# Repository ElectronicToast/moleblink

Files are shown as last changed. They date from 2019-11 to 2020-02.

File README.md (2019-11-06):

# moleblink
  

ATtiny85-based illuminated PCB keychain featuring the Blacker Hovse crest

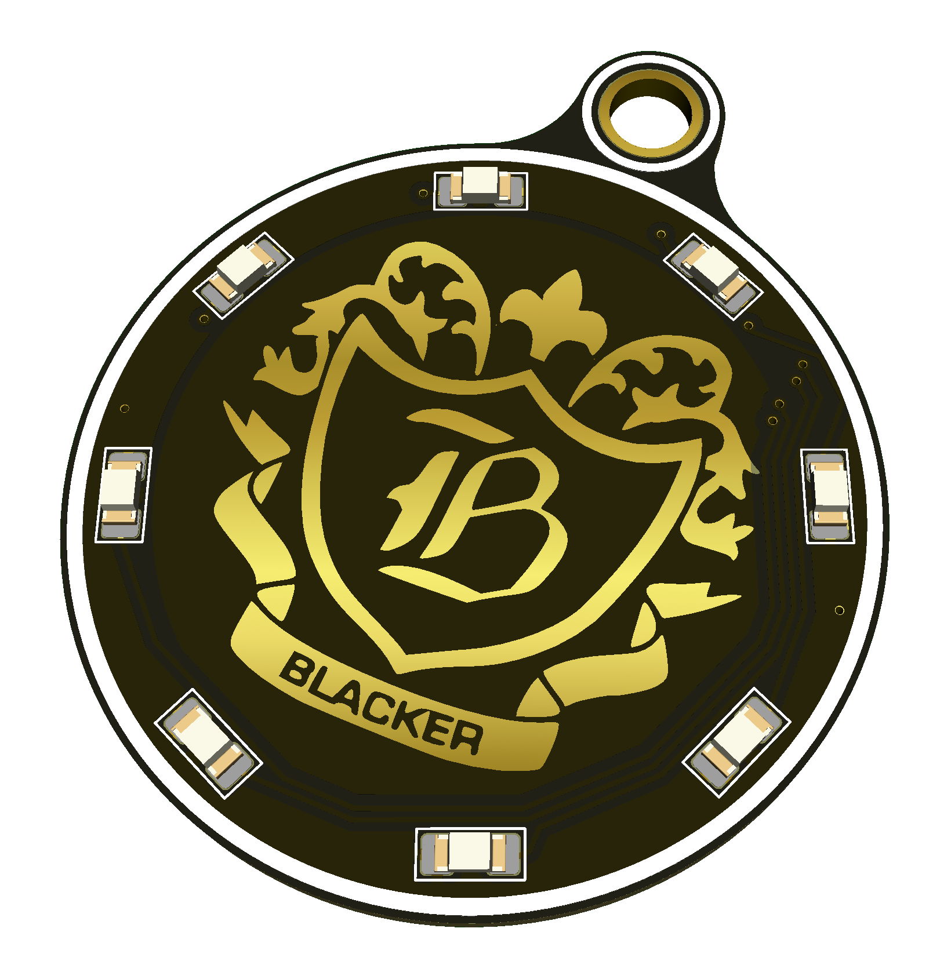
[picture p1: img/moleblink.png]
moleblink


## Description
Blacker Hovse (House) is one of the eight student houses in the undergraduate housing system at Caltech. Blacker was founded in 1932 and named after Robert Roe Blacker, a trustee of Caltech. Notable alumni from Blacker include William Shockley, Walter Munk, Carver Mead, and Kip Thorne. The current house motto is *Sed nvlla nisi ardva virtvs*.

This is a 1.6" by 1.9" PCB keychain featuring the Blacker Hovse crest on the top copper, based on [RuddBlink](https://github.com/ElectronicToast/ruddblink/). A ring of 8 LEDs around the crest is controlled by an ATtiny85 through a 74HC595 shift register. This keychain is intended to be compact and aesthetic, but also simple to solder; all packages are SOIC and 0805 or larger.

The keychain can be powered by a single CR2032 coin cell through the coin cell holder footprint on the back, or through an alternative power source soldered to those pads.

## Features
- ATtiny85 in SOIC-8 package driving 74HC595 shift register in SOIC-16 package
- PWM-able output
- Power switch
- User pushbutton
- MOSFET polarity protection
- PTC fuse
- Aesthetics

## Notes

No input voltage regulation is present. Do not apply more than 5.5 V, the maximum voltage for the ATtiny.

This PCB is designed with KiCad EDA 5.1.4. Schematic and board files may be found under `/moleblink`, with documentation under `/moleblink/doc`.

## Author
- Ray Sun - Undergraduate, Electrical Engineering, Caltech, Class of 2020

## License
<br />Unless otherwise noted, this schematic and PCB design, with associated symbol and footprint files, are licensed under a <a rel="license" href="http://creativecommons.org/licenses/by-sa/4.0/">Creative Commons Attribution-ShareAlike 4.0 International License</a>.

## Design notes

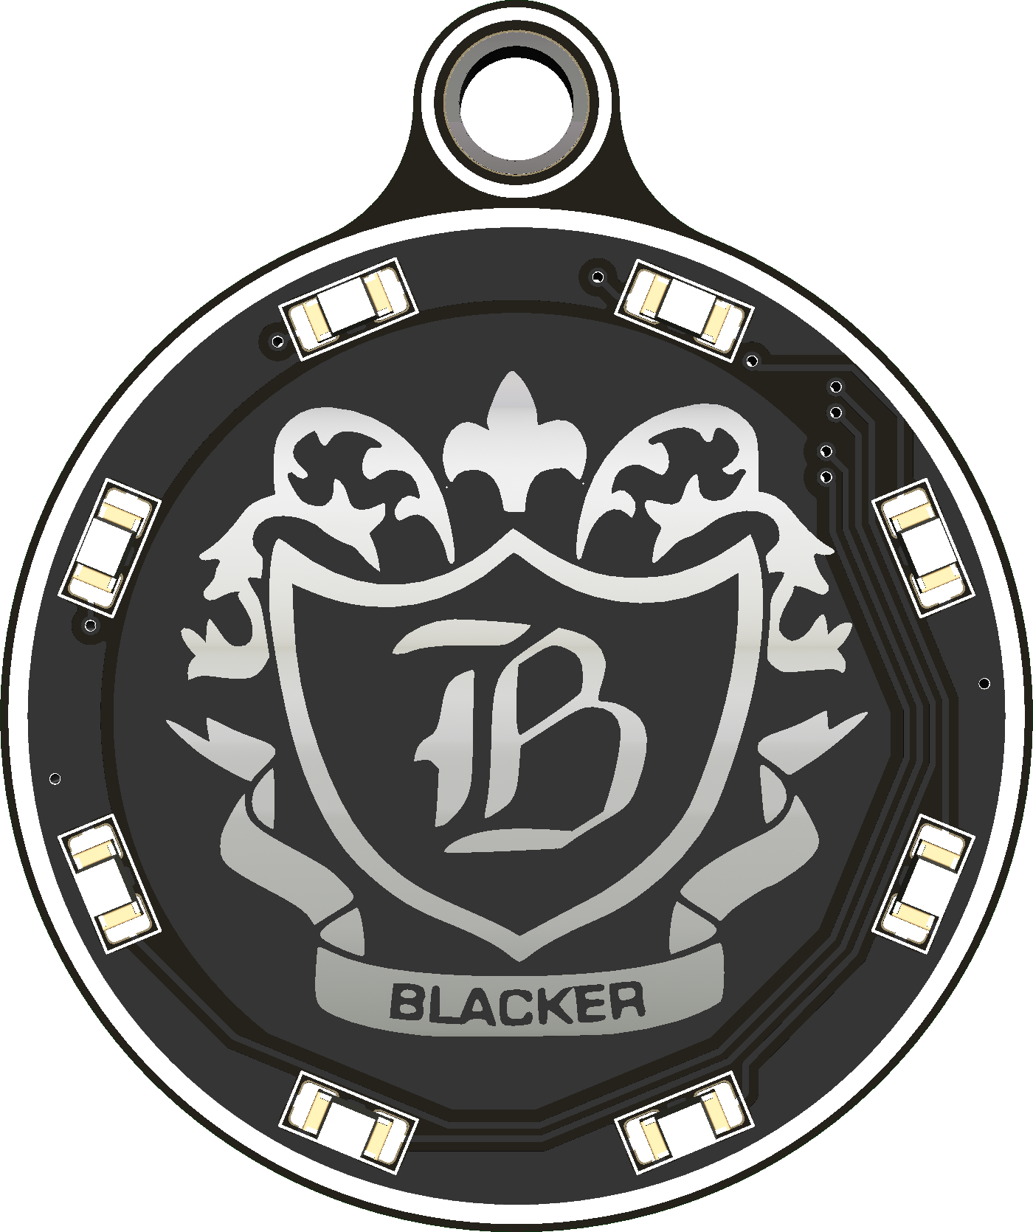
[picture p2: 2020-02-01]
img/moleblink-front.PNG

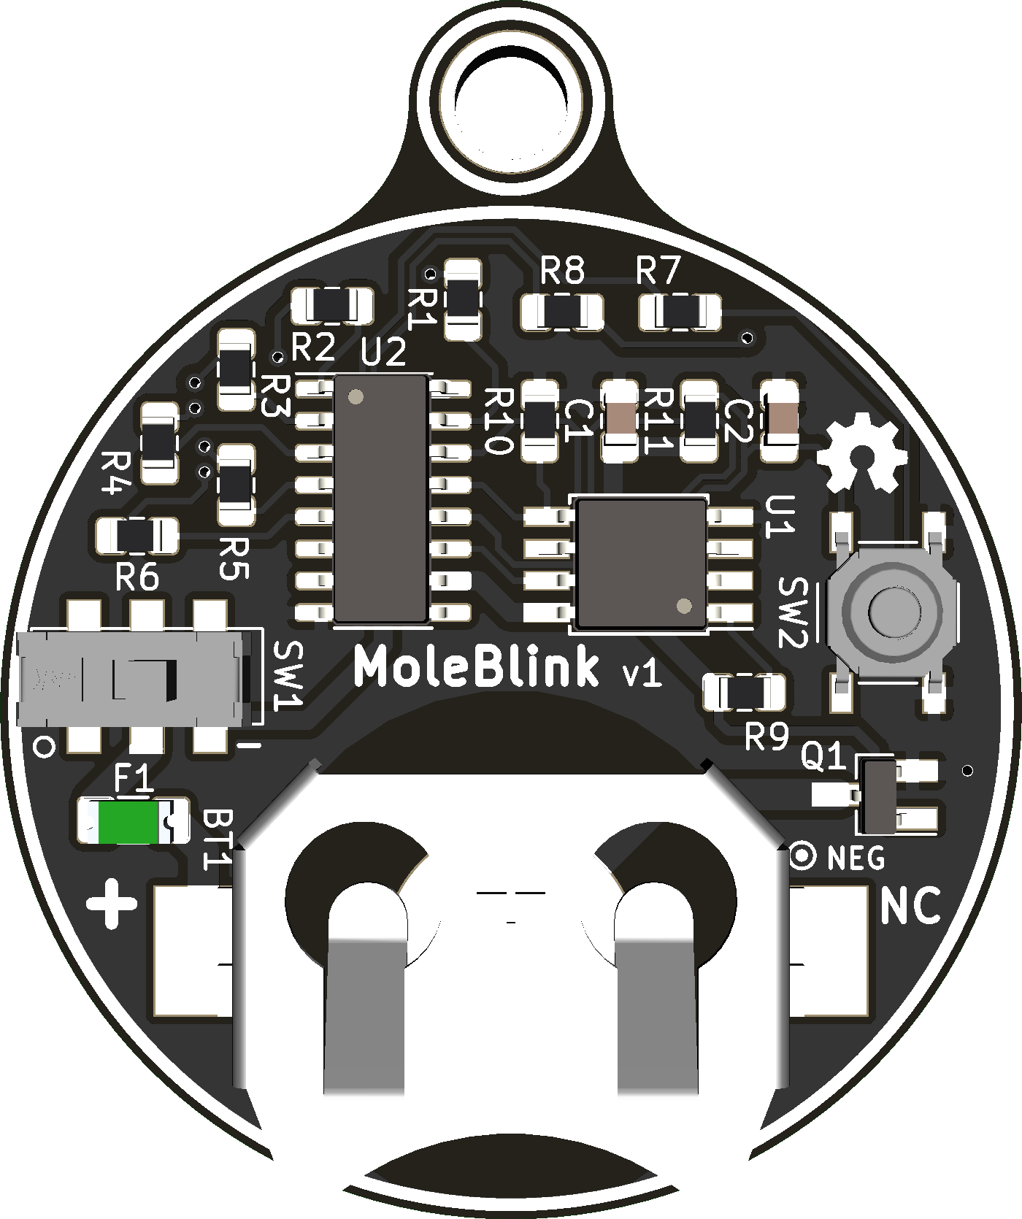
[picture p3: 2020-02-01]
img/moleblink-back.PNG

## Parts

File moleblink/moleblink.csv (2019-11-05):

Source: | ruddblink.sch
Date: | 8/20/2019 22:31
Tool: | Eeschema (5.1.4)-1
Generator: | C:\Program Files\KiCad\bin\scripting\plugins/bom_csv_grouped_by_value_with_fp.py
Component Count: | 29
Ref | Qnty | Value | Cmp name | Footprint | Description | Vendor
BT1, | 1 | 3034 | Battery_Cell | ruddblink:BatteryHolder_Keystone_3034_Wide | Single-cell battery
C1, C2, | 2 | 0.1uF | C_Small | Capacitor_SMD:C_0805_2012Metric_Pad1.15x1.40mm_HandSolder | Unpolarized capacitor, small symbol
D1, D2, D3, D4, D8, D7, D6, D5, | 8 | 150120BS75000 | LED_Small_ALT | ruddblink:LED_1206_Uniform_HandSolder | Light emitting diode, small symbol, filled shape
F1, | 1 | 0ZCJ0005FF2E | Fuse_Small | Fuse:Fuse_1206_3216Metric_Pad1.42x1.75mm_HandSolder | Fuse, small symbol
H1, | 1 | KEYHOLE | MountingHole_Pad | ruddblink:MountingHole_Keyring | Mounting Hole with connection
Q1, | 1 | IRFML8244 | BSS138 | Package_TO_SOT_SMD:SOT-23_Handsoldering | 50V Vds, 0.22A Id, N-Channel MOSFET, SOT-23
R1, R2, R3, R4, R8, R7, R6, R5, | 8 | R | R_Small_US | Resistor_SMD:R_0805_2012Metric_Pad1.15x1.40mm_HandSolder | Resistor, small US symbol
R11, R9, R10, | 3 | 10K | R_Small_US | Resistor_SMD:R_0805_2012Metric_Pad1.15x1.40mm_HandSolder | Resistor, small US symbol
SW1, | 1 | JS202011JCQN | SW_DPDT_x2 | ruddblink:SW_SPDT_CK-JS202011JCQN | Switch, dual pole double throw, separate symbols
SW2, | 1 | PTS526 SK15 SMTR2 LFS | SW_Push | ruddblink:SW_Push_PTS526 | Push button switch, generic, two pins
U1, | 1 | ATtiny85-20SU | ATtiny85-20SU | Package_SO:SOIJ-8_5.3x5.3mm_P1.27mm | 20MHz, 8kB Flash, 512B SRAM, 512B EEPROM, debugWIRE, SOIJ-8
U2, | 1 | 74HC595 | 74HC595 | Package_SO:SOIC-16_3.9x9.9mm_P1.27mm | 8-bit serial in/out Shift Register 3-State Outputs

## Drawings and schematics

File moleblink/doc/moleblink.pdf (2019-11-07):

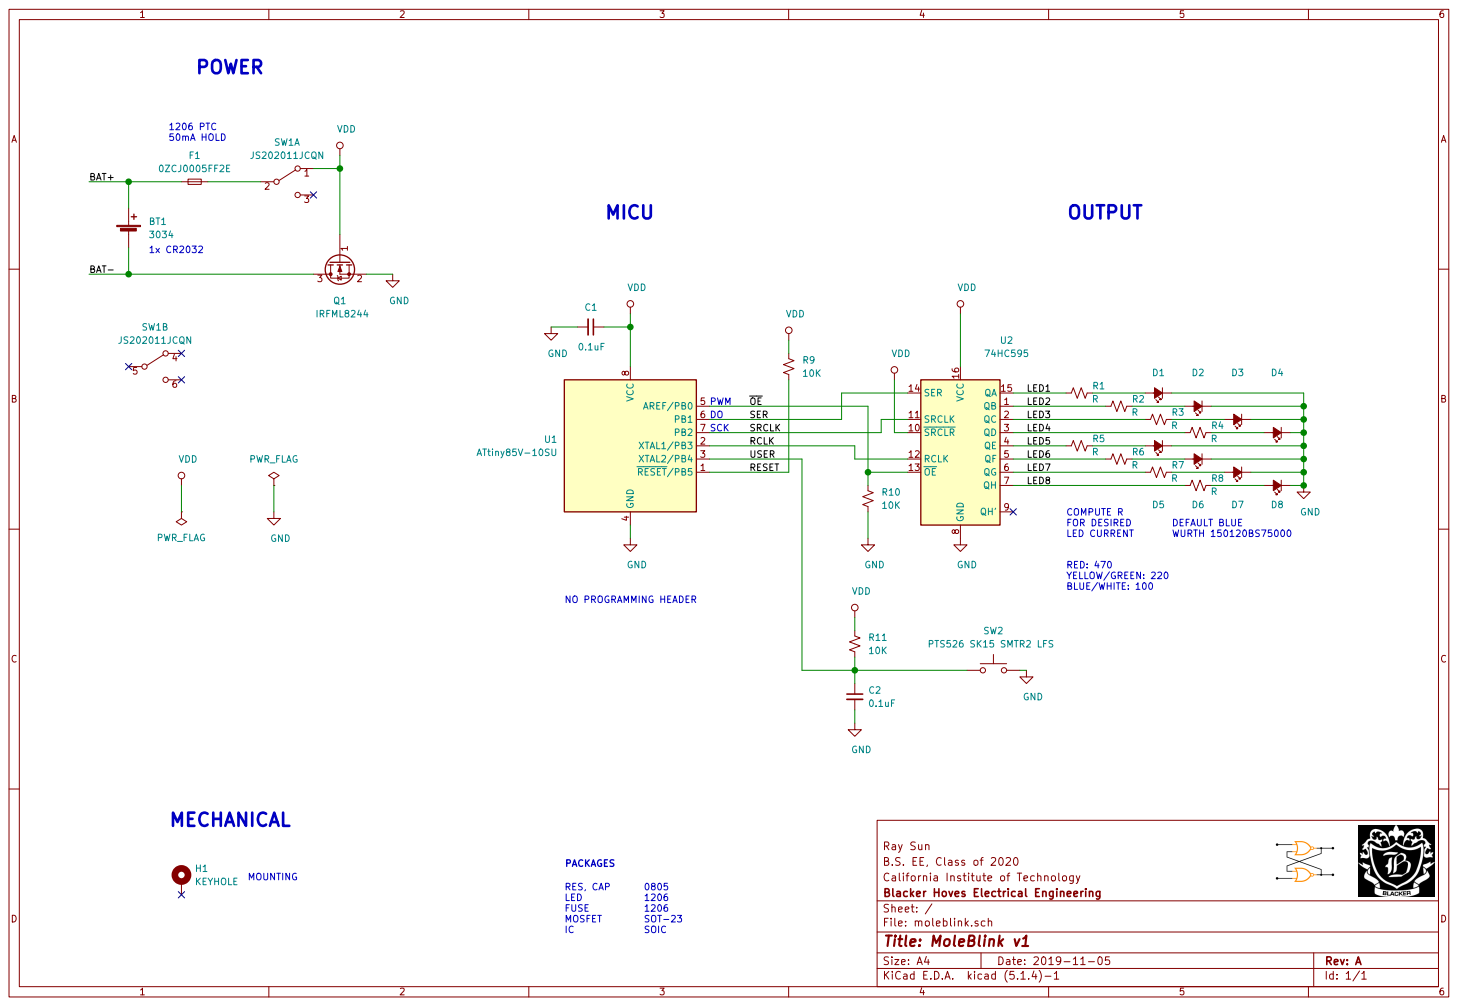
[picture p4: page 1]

PWM
RED: 470 YELLOW/GREEN: 220 BLUE/WHITE: 100 DO
SCK

DEFAULT BLUE WURTH 150120BS75000 PACKAGES RES, CAP

B.S. EE, Class of 2020
California Institute of Technology
File: moleblink.sch Sheet: / Blacker Hoves Electrical Engineering

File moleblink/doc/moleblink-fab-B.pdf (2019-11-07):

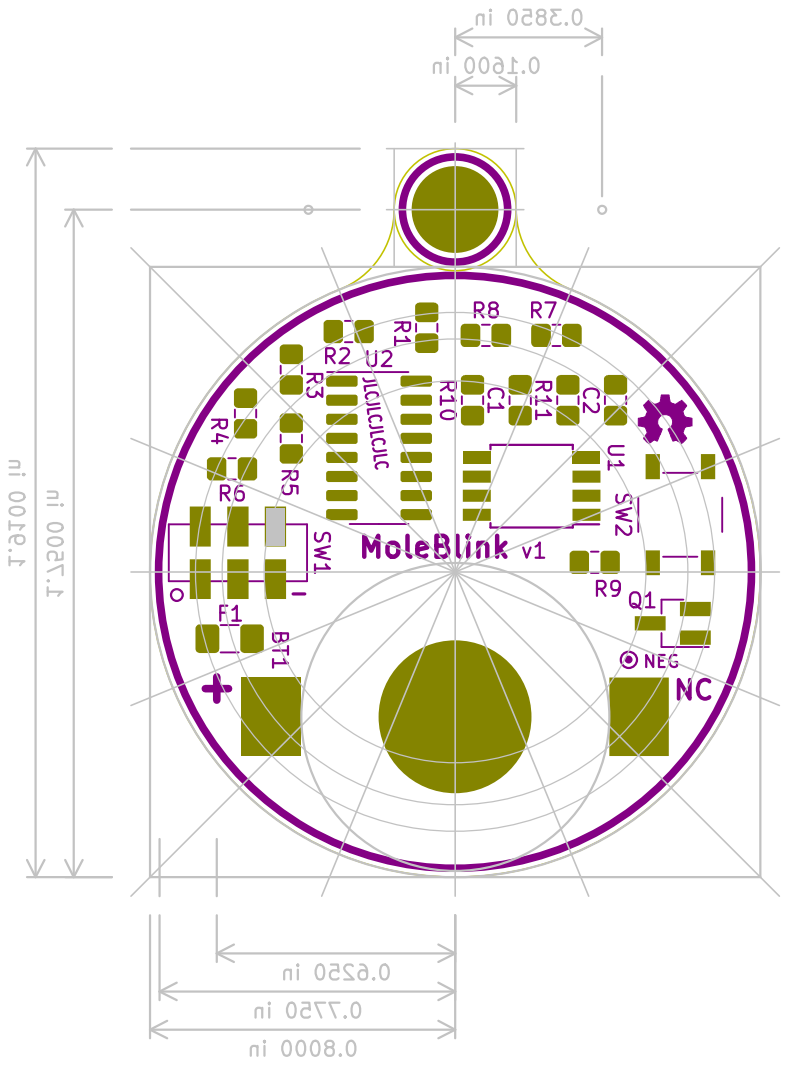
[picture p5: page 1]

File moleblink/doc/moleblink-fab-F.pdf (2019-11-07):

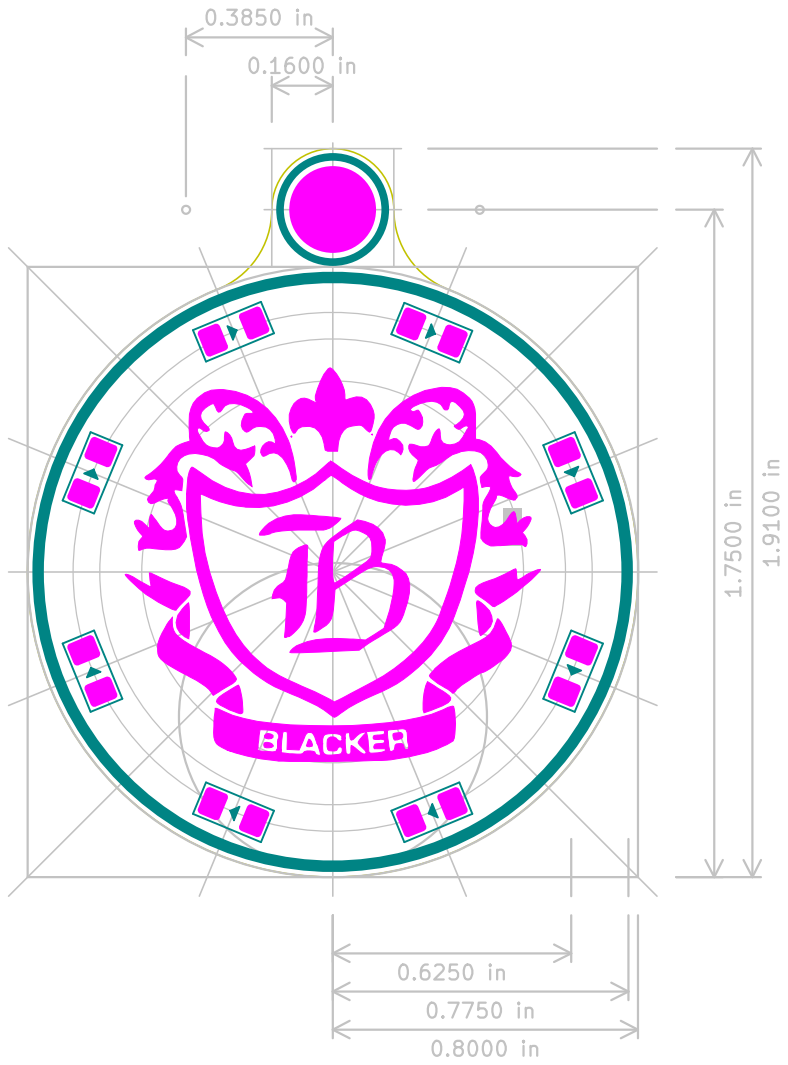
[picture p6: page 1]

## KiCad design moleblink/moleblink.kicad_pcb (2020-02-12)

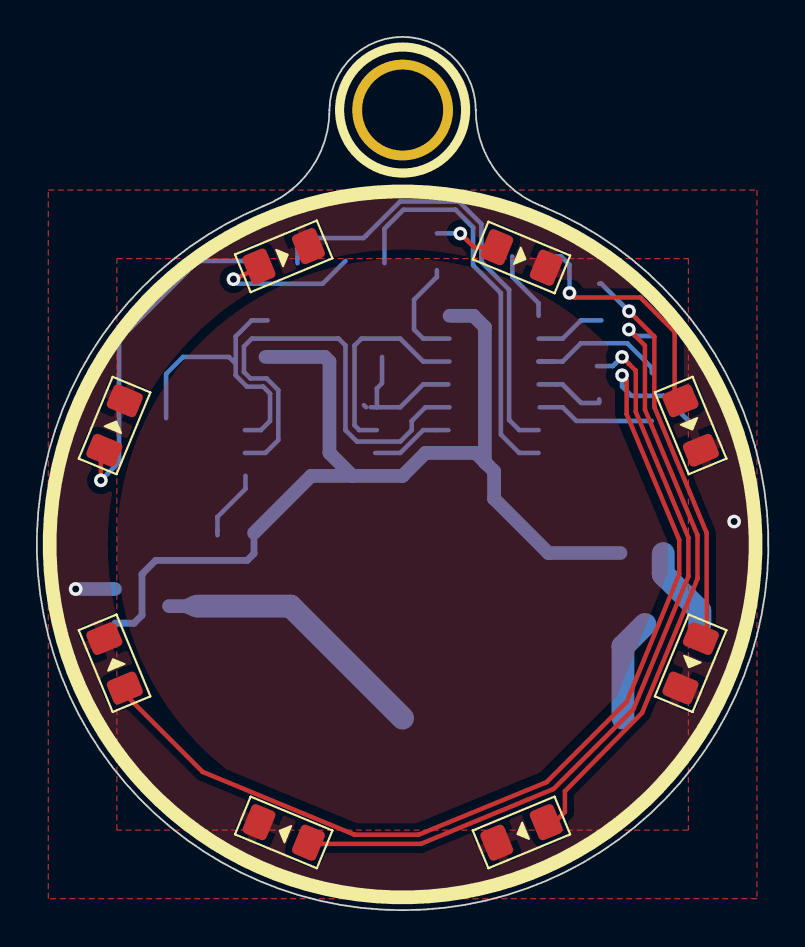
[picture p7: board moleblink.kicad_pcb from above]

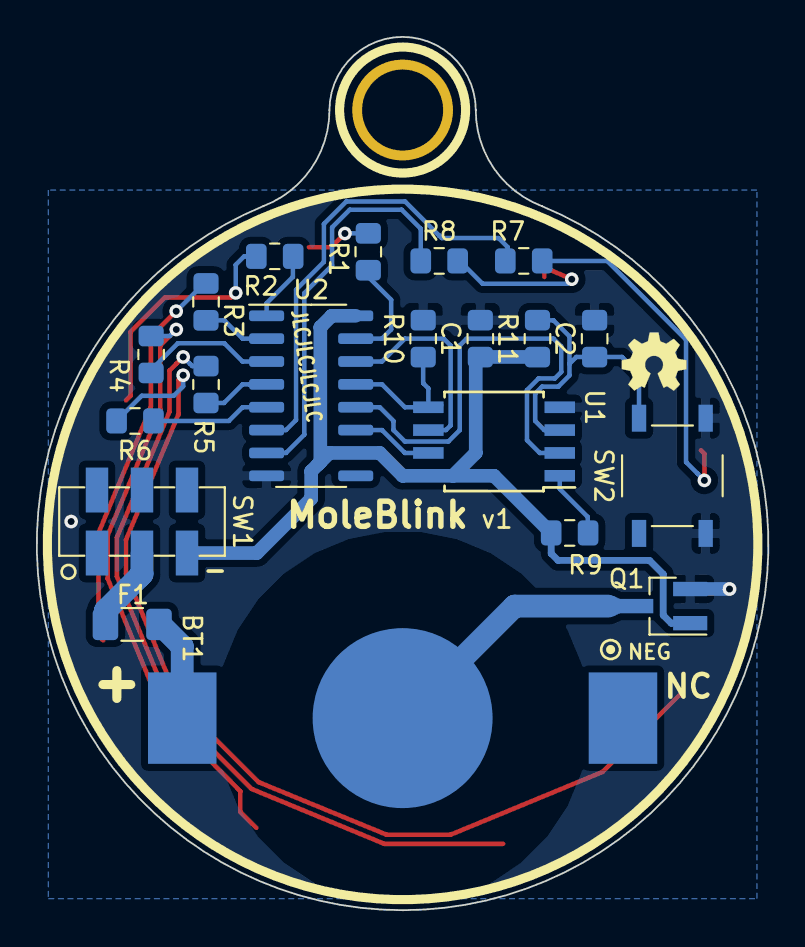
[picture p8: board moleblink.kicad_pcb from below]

Board: 2 copper layers, 40.6 x 48.5 mm, 29 parts (20 on the bottom side), 27 nets.

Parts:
BT1: 3034; BatteryHolder_Keystone_3034_Wide
C1, C2: 0.1uF; C_0805_2012Metric_Pad1.15x1.40mm_HandSolder
D1, D2, D3, D4, D5, D6, D7, D8: 150120BS75000; LED_1206_Uniform_HandSolder
F1: 0ZCJ0005FF2E; Fuse_1206_3216Metric_Pad1.42x1.75mm_HandSolder
H1: KEYHOLE; MountingHole_Keyring
Q1: IRFML8244; SOT-23_Handsoldering
R1, R2, R3, R4, R5, R6, R7, R8: R; R_0805_2012Metric_Pad1.15x1.40mm_HandSolder
R9, R10, R11: 10K; R_0805_2012Metric_Pad1.15x1.40mm_HandSolder
SW1: JS202011JCQN; SW_SPDT_CK-JS202011JCQN
SW2: PTS526 SK15 SMTR2 LFS; SW_Push_PTS526
U1: ATtiny85V-10SU; SOIJ-8_5.3x5.3mm_P1.27mm
U2: 74HC595; SOIC-16_3.9x9.9mm_P1.27mm

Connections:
/BAT+: BT1.1, F1.1
/BAT-: BT1.2, Q1.3
/LED1: R1.1, U2.15
/LED2: R2.1, U2.1
/LED3: R3.1, U2.2
/LED4: R4.1, U2.3
/LED5: R5.1, U2.4
/LED6: R6.1, U2.5
/LED7: R7.1, U2.6
/LED8: R8.1, U2.7
/RCLK: U1.2, U2.12
/RESET: R9.2, U1.1
/SER: U1.6, U2.14
/SRCLK: U1.7, U2.11
/USER: C2.1, R11.2, SW2.1, U1.3
/~OE: R10.1, U1.5, U2.13
GND: C1.2, C2.2, D1.1, D2.1, D3.1, D4.1, D5.1, D6.1, D7.1, D8.1, Q1.2, R10.2, SW2.2, U1.4, U2.8
unnamed: D1.2, R1.2
unnamed: D2.2, R2.2
unnamed: D3.2, R3.2
unnamed: D4.2, R4.2
unnamed: D5.2, R5.2
unnamed: D6.2, R6.2
unnamed: D7.2, R7.2
unnamed: D8.2, R8.2
unnamed: F1.2, SW1.2
VDD: C1.1, Q1.1, R9.1, R11.1, SW1.1, U1.8, U2.10, U2.16

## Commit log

2019-11-05 Add files from RuddBlink
    [moleblink.csv, moleblink.kicad_pcb, moleblink.sch]
2019-11-05 Update schematic
    [moleblink.sch]
2019-11-05 Remove unnecessary footprints
2020-02-12 Neck down the MOSFET drain trace
    [moleblink.kicad_pcb]
